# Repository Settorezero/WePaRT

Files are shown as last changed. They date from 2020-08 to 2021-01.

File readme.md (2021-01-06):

  

# WePaRT

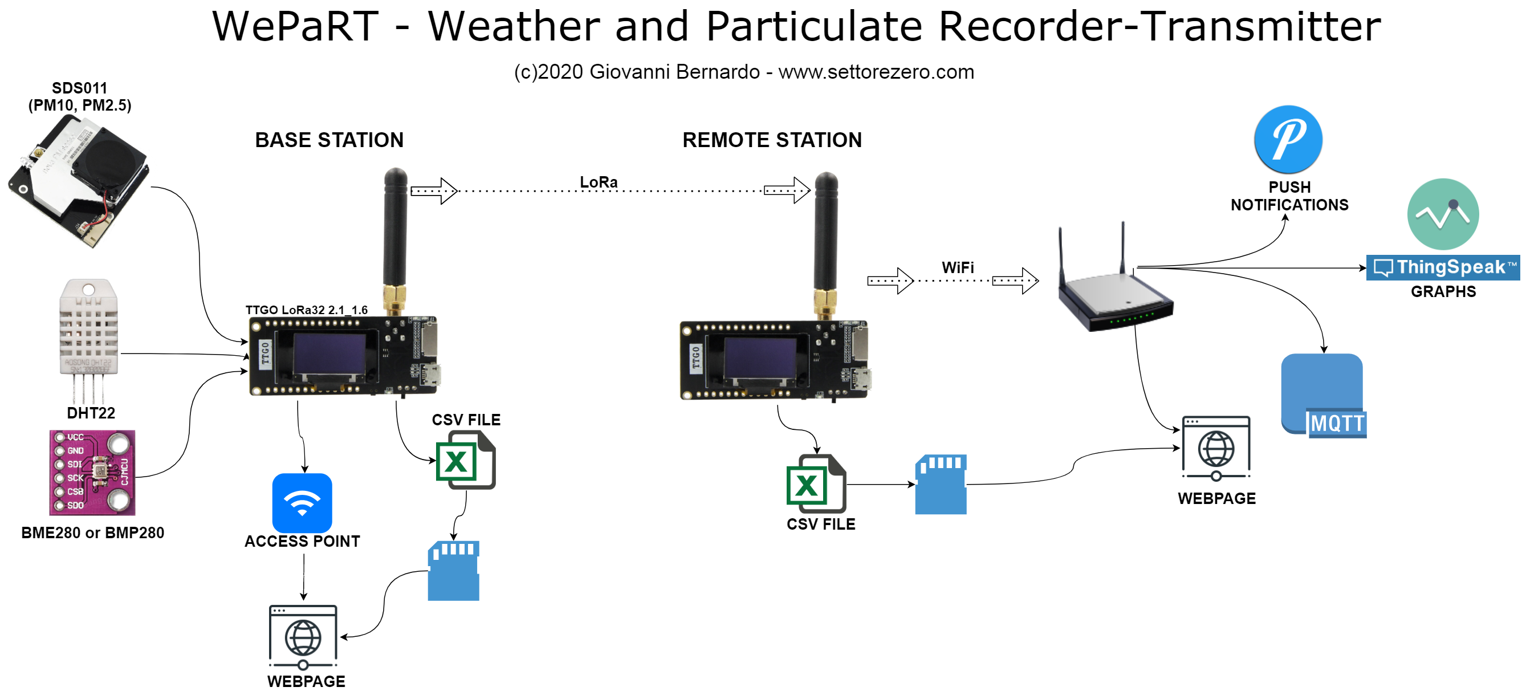
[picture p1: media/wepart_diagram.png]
WePaRT diagram


This project is based on the LiLyGO TTGO LoRa32 version 2.1_1.6 and is composed of two parts:  
- A Base Station
- A Remote Station

### Base Station
Think of this as a station that is placed where WiFi and/or Telephone is not accessible.  
Is the one where sensors are attached. Actually those sensors are used:  
- DHT22 (humidity, temperature)
- BME280 (pressure, temperature, humidity) Or BMP280 (pressure, temperature)
- SDS011 (particulate matter: PM10 and PM2.5)  

Base station gets data from sensors and:
- Save them on a microSD card in CSV format
- propagate them through LoRa to the Remote Station
- act as an access point for showing real-time data on a webpage

### Remote Station
Is the one attached to a WiFi infrastructure. Receives data from the Base Station and:
- transmits them to Thingspeak for graph generation
- transmits them over MQTT
- saves the good received data in a CSV, adding the current time/date taken from an NTP server
- saves the bad received data in a text file for further analisys of bad received packets
- shows a webpage by navigating to his IP address in the same wifi network were device is connected

### Documents
- In the [STL Folder](/stl) are contained the STL parts to be 3D-printed.
- In the [docs Folder](/docs) are contained Datasheets and schematics.
- In the [Arduino Folder](/arduino) are contained the programs to be uploaded on the Stations

### Known Problems
- showing always some data, OLED's pixel burns out so will remain a "shadow". Solution (not yet implemented): a function like a screensaver
- if the connected SD broke up, the station wouldn't start-up since the connected SD can be detected but will fail other functions giving an unexpected behaviour that can lead to a continuos reset. Since the remote station can be placed in a place where is not visibile, if this happens, we will never see a failure: we will see the base station showing always the same data. Solution (not yet implemented): detect a timeout on the base station

### Links
- You can read a full description of the WePaRT on the [settorezero blog](https://www.settorezero.com/wordpress/wepart-stazione-monitoraggio-meteo-polveri-sottili-particolato)
- You can see actual data sent to Thingspeak by our WePaRT [here](https://thingspeak.com/channels/1107465)
- [This](http://www.bahar.asia/Product/26/name?BWP-10008-A2) is the enclosure I've used for the Remote Station

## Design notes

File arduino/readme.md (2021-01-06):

## WePaRT Source Code  

Source code is intended to be used along Arduino IDE.  
There is a source code for the base station and another one for the remote station.
You need to install the ESP32 support for Arduino IDE.

### Libraries to install

- [Thingspeak-Arduino](https://github.com/mathworks/thingspeak-arduino) (by Mathworks)
- [EasyNTPClient](https://github.com/aharshac/EasyNTPClient) (by Harsha Alva)
- [Time](https://github.com/PaulStoffregen/Time) (by Michael Margolis)
- [PubSubClient](https://github.com/knolleary/pubsubclient) (by Nick O’Leary)
- [Adafruit DHT sensor](https://github.com/adafruit/DHT-sensor-library)
- [Adafruit Unified Sensor](https://github.com/adafruit/Adafruit_Sensor)
- [Adafruit BME280](https://github.com/adafruit/Adafruit_BME280_Library)
- [LoRa](https://github.com/sandeepmistry/arduino-LoRa) (by Sandeep Mistry)
- [ESP8266 and ESP32 Oled Driver for SSD1306 Displays+](https://github.com/ThingPulse/esp8266-oled-ssd1306) (by ThingPulse)

If you want to use Pushover for Push Notifications, you must install also [Pushover by Arduino Hannover](https://github.com/ArduinoHannover/Pushover). You can copy the two files Pushover.cpp and Pushover.h in the `wepart_remote_station/` folder

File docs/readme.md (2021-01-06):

## WePaRT DOCS and LINKS

In this folder are located the useful documents and links for better working with the WePaRT.  

### Documents
- [Base Station Schematic](schematic_base_station.png)
- [SDS011 Datasheet](SDS011_datasheet.pdf)
- [SDS011 Protocol Specifications, Rev. 1.3](SDS011_Protocol_V1.3.pdf)
- [BME280 Datasheet](bme280_datasheet.pdf)
- [BME280 Design guide](bme280_design_guide.pdf)
- [LiLyGO TTGO LoRa32 2.1_1.6 Schematic](LoRa32_schematic.pdf)

### Links
- [SDS11 - things to know](https://www.settorezero.com/wordpress/il-sensore-sds011-e-le-polveri-sottili/)
- [BME280, BMP280 - things to know](https://www.settorezero.com/wordpress/sensori-di-pressione-bme280-e-bmp280/)
- [The LiLyGO TTGO LoRa 2.1_1.6 - Part 1](https://www.settorezero.com/wordpress/lora_lorawan_lilygo_ttgo_lora32_esp32/)
- [The LiLyGO TTGO LoRa 2.1_1.6 - Part 2](https://www.settorezero.com/wordpress/lilygo_ttgo_lora32_esp32_point_to_point/)

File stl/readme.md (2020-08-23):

## WePaRT STL Files
In this folder are placed the STL files we used for the WePaRT.  
There are 2 STL Files created by @CyB3rn0id and another to be downloaded from Thingiverse.

### STL Files
- [funnel](funnel.stl) - This is used as air conveyour
- [funnel grid](funnel_grid.stl) - Simple grid to be placed on top of funnel

### Thingiverse
- [Stevenson Screen by cybershifter](https://www.thingiverse.com/thing:4529099/files)

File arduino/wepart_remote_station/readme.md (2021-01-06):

## WePaRT Remote Station source code

This is the code you must upload on the module in the Remote Station. The Remote Station is the one connected to WiFi and that receives data over LoRa from the Base for sending them over MQTT and Thingspeak, aka the Receiver Station.

Please remember those things first than upload the code:  
- Remove the microSD card from the slot
- Select the right board in Arduino IDE: <kbd>ESP32 Arduino > TTGO LoRa32-OLED v1</kbd>
- Select the right COM port in Arduino IDE
- Install the right libraries
- change the values in `secret.h` by putting your username/password for WiFi, and eventually for Thingspeak, MQTT Pushover

If you don't want to use Thingspeak comment `#define USE_THINGSPEAK` at row `118` of `wepart_remote_station.ino`.
If you don't want to use MQTT comment `#define USE_MQTT` at row `128` of `wepart_remote_station.ino`.
If you don't want to use Pushover comment `#define USE_PUSHOVER` at row `123` of `wepart_remote_station.ino`.

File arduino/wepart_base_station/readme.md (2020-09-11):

## WePaRT Base Station source code

This is the code you must upload on the module in the Base Station. The Base Station is the one where Sensors are attached, aka the Transmitter Station.  

Please remember those things first than upload the code:  
- Remove the connection between SDS011 and board. The SDS011 implementation uses the hardware UART, the same used for code upload
- Remove the microSD card from the slot
- Select the right board in Arduino IDE: ESP32 Arduino > TTGO LoRa32-OLED v1
- Select the right COM port in Arduino IDE
- Install the right libraries

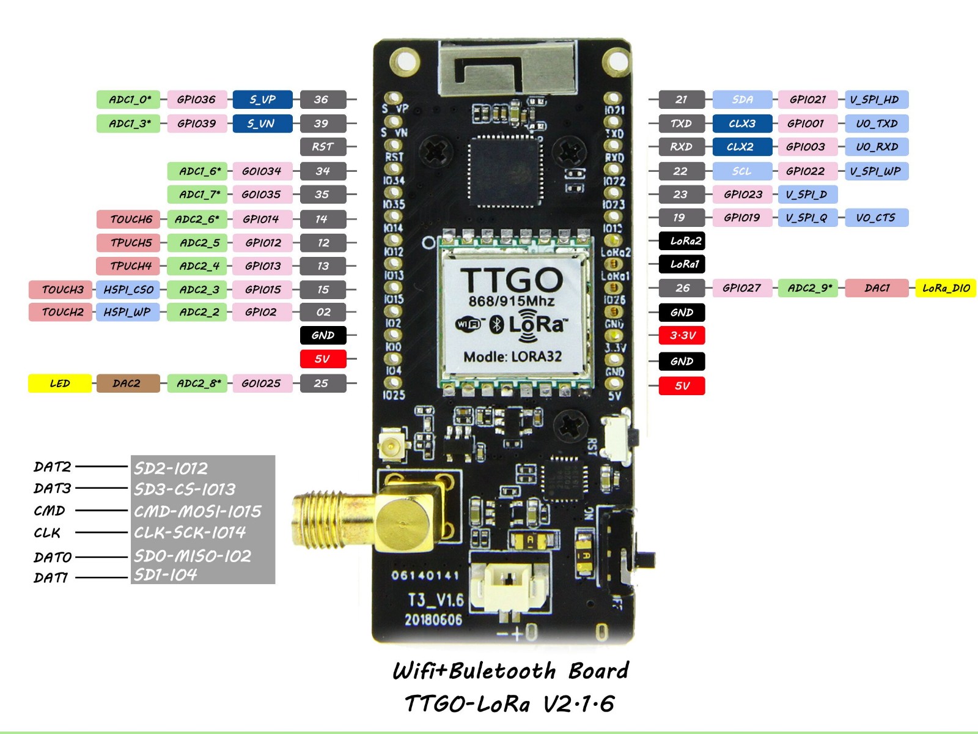
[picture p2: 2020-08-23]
docs/LoRa32_pinout.jpg

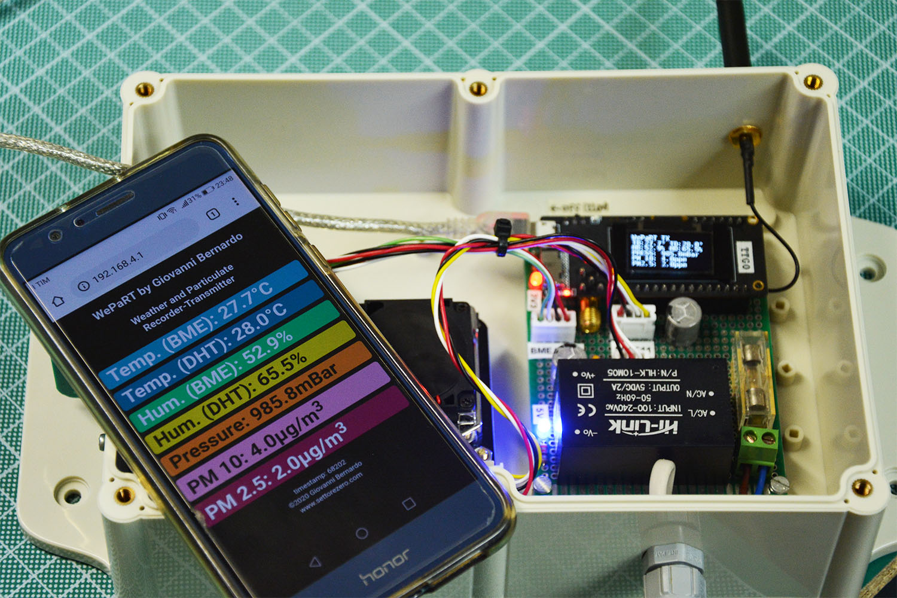
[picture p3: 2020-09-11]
media/wepart_overview.jpg

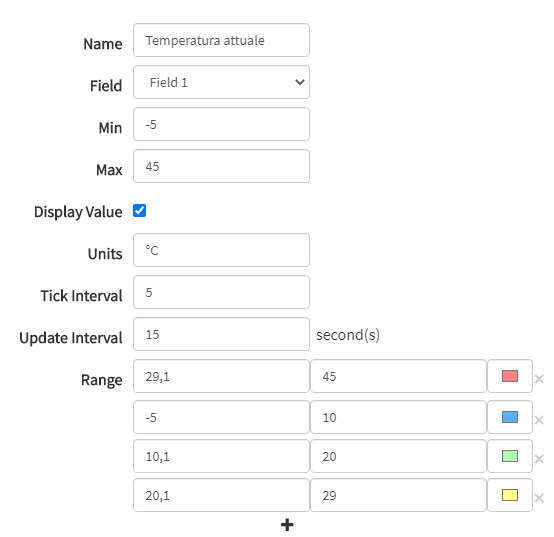
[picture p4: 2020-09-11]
media/thingspeak_gauge_settings.png

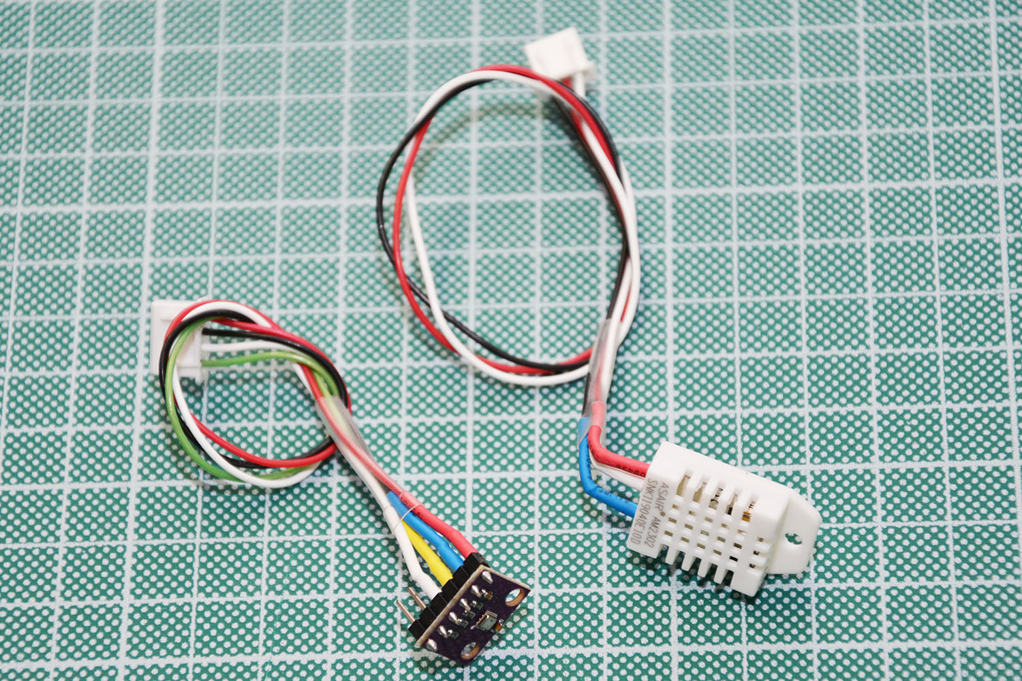
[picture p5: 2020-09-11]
media/wepart_meteo_sensors.jpg

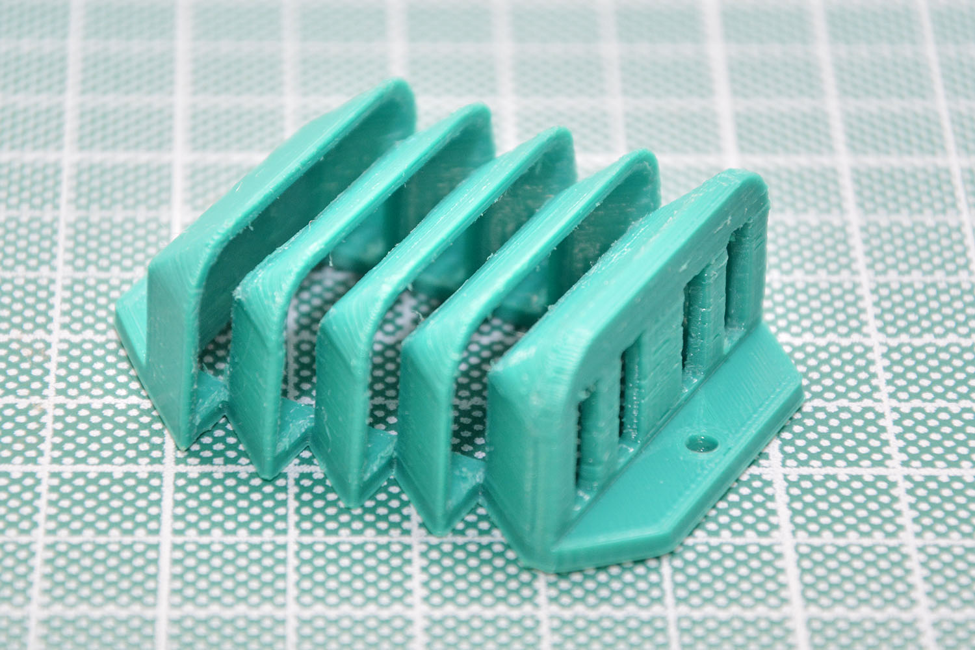
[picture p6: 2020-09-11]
media/wepart_stevenson_screen.jpg

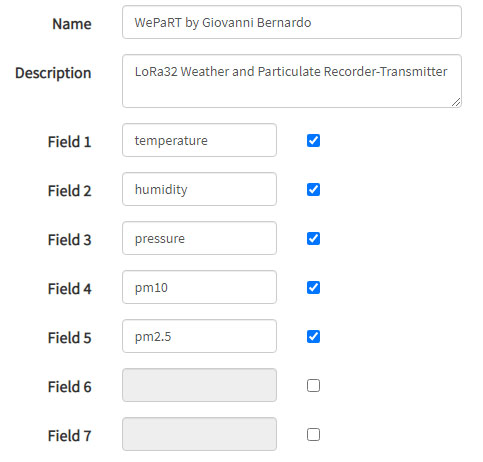
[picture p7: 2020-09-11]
media/thingspeak_channel_settings.jpg

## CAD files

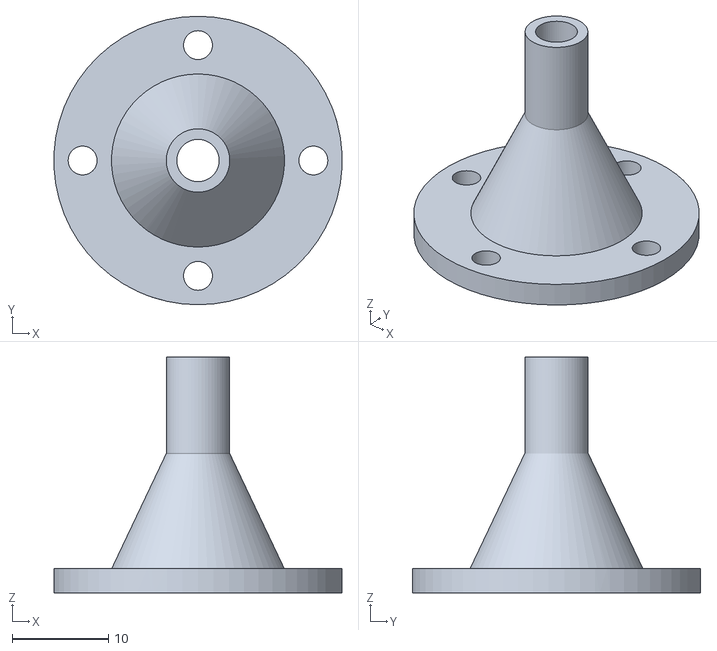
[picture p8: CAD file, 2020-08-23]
stl/funnel.stl
30.0 x 30.0 x 24.5

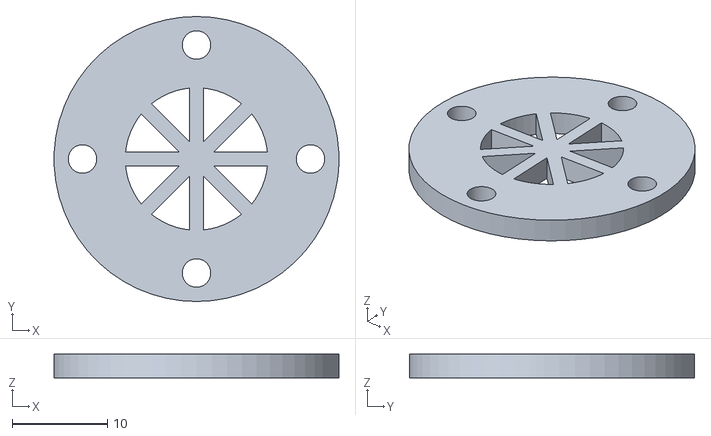
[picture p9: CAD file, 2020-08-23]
stl/funnel_grid.stl
30.0 x 30.0 x 2.50

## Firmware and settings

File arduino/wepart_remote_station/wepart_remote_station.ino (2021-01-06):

/*
 * WePaRT - Weather and Particulate Recorder Transmitter
 * REMOTE STATION
 * Version 1.1
 * board used: LILYGO® TTGO LoRa32 V2.1_1.6
 * 
 * Code and design by Bernardo Giovanni aka CyB3rn0id (https://www.settorezero.com)
 * If you want to share the code please mention: Giovanni Bernardo of settorezero.com
 * after sending me a message
 *
 * For further information please read the article at:
 * https://www.settorezero.com/wordpress/wepart-stazione-monitoraggio-meteo-polveri-sottili-particolato
 *
 * Repo URL:
 * https://github.com/Settorezero/WePaRT
 * 
 * Select the board ESP32 Arduino > TTGO LoRa32-OLED v1 
 *
 * Libraries required for this part of code:
 * Adafruit DHT Sensor: https://github.com/adafruit/DHT-sensor-library
 * Adafruit Unified Sensor: https://github.com/adafruit/Adafruit_Sensor
 * Adafruit BME280: https://github.com/adafruit/Adafruit_BME280_Library
 * LoRa by Sandeep Mistry: https://github.com/sandeepmistry/arduino-LoRa
 * ESP8266 and ESP32 Oled Driver for SSD1306 Displays by Thingpulse: https://github.com/ThingPulse/esp8266-oled-ssd1306
 * EasyNTP client - https://github.com/aharshac/EasyNTPClient
 * PubSub client - https://github.com/knolleary/pubsubclient
 * TimeLib - https://github.com/PaulStoffregen/Time
 * Thingspeak - https://github.com/mathworks/thingspeak-arduino
 * 
 * If you want to use Pushover for Push Notifications, you must install also
 * Pushover by Arduino Hannover - https://github.com/ArduinoHannover/Pushover
 * (you can copy the two files Pushover.cpp and Pushover.h in this folder)
 *
 * LICENSE
 * Attribution-NonCommercial-ShareAlike 4.0 International 
 * (CC BY-NC-SA 4.0)
 * 
 * WARNING: this license may be valid for the project (design, schematics, diagrams, own documentation, solutions to problems, ideas)
 * and for my own written code (some routines and ideas). 
 * Is not appliable for used libraries and commercial used hardware.
 * Please read licenses for every library used and hardware.
 * 
 * This is a human-readable summary of (and not a substitute for) the license:
 * You are free to:
 * SHARE — copy and redistribute the material in any medium or format
 * ADAPT — remix, transform, and build upon the material
 * The licensor cannot revoke these freedoms as long as you follow the license terms.
 * Under the following terms:
 * ATTRIBUTION — You must give appropriate credit, provide a link to the license, 
 * and indicate if changes were made. You may do so in any reasonable manner, 
 * but not in any way that suggests the licensor endorses you or your use.
 * NON COMMERCIAL — You may not use the material for commercial purposes.
 * SHARE ALIKE — If you remix, transform, or build upon the material,
 * you must distribute your contributions under the same license as the original.
 * NO ADDITIONAL RESTRICTIONS — You may not apply legal terms or technological 
 * measures that legally restrict others from doing anything the license permits.
 * 
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
 * Please read the Full License text at the following link:
 * https://creativecommons.org/licenses/by-nc-sa/4.0/legalcode
 *
 */

#include <WiFi.h>
#include <WebServer.h>
#include <SD.h>
#include <SPI.h>
#include <LoRa.h>
#include <Wire.h> 
#include <SSD1306Wire.h>
#include <WiFiUdp.h>
#include <EasyNTPClient.h>
#include <TimeLib.h>
#include <PubSubClient.h>
#include "ThingSpeak.h"

#include "board_defs.h" // in this header I've defined the pins used by the module LILYGO® TTGO LoRa32 V2.1_1.6
#include "images.h"
#include "my_fonts.h"
#include "webpage.h"
#include "secret.h"

// If you want to use Pushover for Push Notifications, you must install also
// Pushover by Arduino Hannover - https://github.com/ArduinoHannover/Pushover
// (you can copy the two files Pushover.cpp and Pushover.h in this folder)
#include "pushover.h"

// START OF CUSTOMIZE SECTION --------------------------------------------------------------------------------------------------------------------

// **************************************
// WI-Fi Network settings
// **************************************
#define RETRIES_WIFI 100  // number of WiFi re-connection retries after a no-connection, at 500mS reconnection rate
#define USE_STATIC_IP // comment for using DHCP OR if you have errors on NTP server connection
// if you want to use static IP, change also following parameters:
// WARNING:
// the better thing is to assign static IP directly from the router
#ifdef USE_STATIC_IP
    IPAddress deviceIP(192, 168, 1, 162); // static address will be assigned to the device
    IPAddress gateway(192, 168, 1, 1); // router address
    IPAddress subnet(255, 255, 255, 0); // subnet mask, usually you don't need to change this value
    // following are Google DNS, you don't really need to change them
    IPAddress dns1 (8, 8, 8, 8); // first DNS, required for easyntp with static ip (https://github.com/aharshac/EasyNTPClient/issues/4)
    IPAddress dns2 (8, 8, 4, 4); // second DNS, required for easyntp with static ip
#endif

// **************************************
// THINGSPEAK settings
// **************************************
#define USE_THINGSPEAK // comment if you don't want to use thingspeak

// **************************************
// PUSHOVER settings
// **************************************
#define USE_PUSHOVER // comment if you don't want to use pushover

// **************************************
// MQTT settings
// **************************************
#define USE_MQTT // comment if you don't use an MQTT server
#define MQTT_RETRIES 5  // number of MQTT re-connection retries after a no-connection
#define MQTT_SOCKET_TIMEOUT 2 // seconds for MQTT server response timeout
#define MQTT_USE_PASSWORD // Comment this if your MQTT server does not require user/password
IPAddress mqtt_server(192,168,1,101); // this is the address of your MQTT server
const uint16_t mqtt_port=1883; // this is the port where your MQTT server is listening. 1883 is the standard value
const char* mqtt_clientID = "WePaRT"; // unique name for this MQTT client, you can leave WePaRT
const char* topic_wepart="wepart"; // MQTT topic where message will be published

// **************************************
// NTP settings
// **************************************
// WARNING: use DHCP (NO static IP) if you encounter problems with NTP server
// NTP server returns UTC time. Italy use the CET (Central European Time). 
// during the ST (Standard Time="ora solare" in italian language) CET=UTC+1
// during the DST (Daylight Saving Time="ora legale" in italian language) CET=UTC+2
// DST starts at 2:00AM of the last Sunday of March and ends at 3:00AM of the last Sunday of October
#define TIME_OFFSET 1 // local time offset during Standard Time (Italy uses CET=UTC+1)
const char* NTPServer="it.pool.ntp.org"; //"ntp1.inrim.it";  // NTP server, use one of your country
#define NTP_RETRY_MINUTES 10  // if first NTP connection gone bad, I'll retry after those minutes

// **************************************
// OTHER settings
// **************************************

// uncomment for verbose messages on the serial port (115200 baud)
#define DEBUG

// remove comment if you want a fast-startup (no delays, nor logos during initializazion - used mainly for a rapid check of the code after debug)
//#define FASTINIT

// normal pressure at 25° at my altidude
// I used the calculator at https://www.mide.com/air-pressure-at-altitude-calculator
// not used in the code, here for future implementations
float nPressure=983.4253; // hPa = mBar

// pm10, pm2.5 limits for pushover notifications
float pm10limit=40;
float pm25limit=20;

// END OF CUSTOMIZE SECTION ----------------------------------------------------------------------------------------------------------------------
// do not change nothing below

// variables used for this (remote) station
bool sdpresent=false; // keep in mind if there is an SD card mounted
String rssi = "--"; // received signal strength indicator value
float mybattery=0; // battery voltage on this device (not the base station)
bool datavalid=false; // keep in memory if received packet over LoRa is good
String dataFile=""; // file name where data will be saved on the SD card
bool firstStart=true; // used for first time file-creation on first valid received data
const char* badPacketFile="/badpack.txt"; // file where bad packets will be saved, don't forget the / in front of filename!

// variables used for Time keeping
bool clockIsSet=false; // flag that indicates that the time was updated the first time at startup
int8_t prevDay=-1; // used for time refresh once a day or for forcing time update
String wd[7]={"dom","lun","mar","mer","gio","ven","sab"}; // name of weekdays, 9 chars max length in italian
String mo[12]={"Gen","Feb","Mar","Apr","Mag","Giu","Lug","Ago","Set","Ott","Nov","Dic"}; // name of months

// good received data from base station
uint8_t fields=0; // number of transmitted fields
String basetimestamp=""; // timestamp from remote station
String battery="-.-"; // base station battery voltage
String sdstatus="-"; // base station SD status: -1=not mounted, 0=full, 1=working
// data from BME280/BMP280
String pressure="---.-";
String temperatureB="--.-";
String humidityB="--.-"; // not used if your base station has the BME280 instead of the BMP280
// data from DHT22
String temperatureD="--.-";
String humidityD="--.-";
// data from SDS011
String pm10="---";
String pm25="---";
String pmIsNew="0";
bool stoprecording=false; // for future use to stop the SD saving
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
void loop() 
  {
  static bool lastDst=checkDST(); // DST status, used for forcing time update since normally will occur after 00:00
 
  // check for wifi/MQTT connection
  wl_status_t wifiStatus = WiFi.status();
  if(wifiStatus != WL_CONNECTED)
    {
    wifi_connect();
    }
  #ifdef USE_MQTT
  else if (!MQTTClient.loop()) // needed for mantaining MQTT connection, returns connection status
      {
      #ifdef DEBUG
        Serial.println("MQTT disconnected");  
      #endif
      #ifdef MQTT_USE_PASSWORD
          MQTTClient.connect(mqtt_clientID,mqtt_user,mqtt_password);
      #else
          MQTTClient.connect(mqtt_clientID);
      #endif
      }
  #endif

  // doing the Webserver required stuff
  server.handleClient();
  
  // check if clock update if needed every hour
  if (clockIsSet) 
    {
    bool dst=checkDST(); // check if we're in DST for forcing time update
    if (lastDst!=dst)
      {
      if(updateTime(true)) lastDst=dst;
      }
   else
      {
      updateTime(false); // normal update once a day after 00:00
      }
    } // \clockIsSet
  else
    {
    if(updateTime(true)) lastDst=checkDST();
    }
    
   // write stuff on the oled display
  display.clear();
  display.setTextAlignment(TEXT_ALIGN_LEFT);
  display.setFont(Monospaced_bold_11);
  display.drawString(0,0, "WePaRT RX ["+rssi+"]");
  display.drawString(0, 10,"TB:"+temperatureB+"° TD:"+temperatureD+"°"); // temperature from the BME280/BMP280 - Temperature from the DHT22
  if (fields==12)
    {
    display.drawString(0, 20,"HB:"+humidityB+"% HD:"+humidityD+"%"); // humidity from the BME280 - Humidity from the DHT22
    }
  else
    {
    display.drawString(0, 20,"Hu: "+humidityD+"%"); // humidity from the DHT22
    }
  display.drawString(0, 30,"PRESS: "+pressure+"mBar"); // pressure
  display.drawString(0, 40,"PM 10: "+pm10+"ppm"); // PM10 value (whole, contains also the PM2.5)
  display.drawString(0, 50,"PM2.5: "+pm25+"ppm"); // PM2.5 value
  display.display();

  int packetSize=LoRa.parsePacket();
  if (packetSize) getLoRaPacket(packetSize);
  }

/******************************************************************************************************************
* Receive LoRa Packet and transmit data
******************************************************************************************************************/
void getLoRaPacket(int packetSize) 
  {
  datavalid=false; // become true?
  LedOn();
  String packet=""; // reset the received packet string
  String error=""; // error description if any
  String packetField[13]; // separate fields of the packet
  String packSize=String(packetSize,DEC); // bytes of the packet (was passed to the function)
  rssi=String(LoRa.packetRssi(), DEC); // received signal strength indicator
  // re-construct packet char by char
  for (int i=0; i<packetSize; i++) 
    {
    packet +=(char)LoRa.read(); 
    }
  
  #ifdef DEBUG
    Serial.print("Packet received: ");
    Serial.println(packet);
    Serial.print("RSSI: ");
    Serial.println(rssi);
  #endif

  // set the timestamp first than all other things
  String mytimestamp=setNiceTimeStamp();
    
  // packet must start with @ and end with #
  if ((packet.startsWith("@") && packet.endsWith("#")))
    {
    // Received packet is composed as:
    // https://docs.google.com/spreadsheets/d/1uwv2ZbNlVsGTnG6Q6OH3sNCoVa-4uajZjfyRlMmH_ik/edit?usp=sharing
   
    // I must remove the @ and the #
    String upacket=packet.substring(1,packet.length()-1);
    
    // parse the packet
    int cc=0; // field separator counter
    int k=-1; // first substring must start from index 0 and I add 1 for others
    // scanning in search of separators one char at time
    for (int i=0; i<upacket.length(); i++) 
        {
        if (upacket.substring(i, i+1)==";") // found the field separator
            {
            packetField[cc]=upacket.substring(k+1,i); // extract field from next char after previous comma until this char
            k=i; // keep in mind the position of last ; found
            cc++; // ; counter is the same of field counter
            } // \; found
        } // \for
    
    // last element has no ; after it and it's the checksum value. I must extract it from the last ; to the end of the string
    packetField[cc]=upacket.substring(k+1,upacket.length());
    
    // scan for null characters in the packets (I don't use them in my packet)
    bool nullChars=false;
    for (int o=0; o<cc+1; o++) // scan all packets
      {
      for (int p=0; p<packetField[o].length(); p++) // scan single packet chars
        {
        if ((packetField[o].charAt(p)<32) || (packetField[o].charAt(p)==127))
          {
          nullChars=true;
          break;      
          }
        }
      if (nullChars) break;
      }

    // if there are no null chars I can continue
    if (!nullChars)
      {
      // check the checksum (lol)
      uint16_t chkR=packetField[cc].toInt(); // checksum contained in the packet (last field), number format
      uint16_t chk=myChecksum(upacket.substring(0,upacket.lastIndexOf(';'))); // calculate actual packet checksum excluding last part with comma and checksum
      if (chk==chkR)
        {
        datavalid=true; // 'till now, data seems valid
        }
      else
        {
        error="Checksum Error. In packet:"+String(chkR)+" Calculated:"+String(chk);
        }
    
      // check the number of fields in the packet
      // number of transmitted fields is the first (0) field
      // number of counted fields is the variable cc, that counts the number of field separators
      if (datavalid)
        {
        uint8_t u=0;
        if (packetField[0]=="12") 
          {u=12;}
        else if (packetField[0]=="11")
          {u=11;}
    
        if (cc==u)
            {
            datavalid=true; // data are really valid
            fields=u; // number of fields
            }
        else    
            {
            datavalid=false; // sorry... reassign false to datavalid
            error="Bad fields count. In packet:"+packetField[0]+" counted:"+String(cc);
            }
        } // checksum ok, i checked the fields number
      } // !nullChars
    else
      {
      // there are nullchars
      datavalid=false;
      error="Null chars in packet";
      }
   } // correct header and tail
  else
    {
    //not correct head and tail
    error="Missing delimiters";
    }

  // data valid => transfer in global used variables, record a new packet on the SD, send data to the world
  if (datavalid)
    {
    basetimestamp=packetField[1];
    temperatureB=packetField[2];
    temperatureD=packetField[3];
    if (fields==12) // base station has the BME280, so there is humidity value from it
        {
        humidityB=packetField[4];
        humidityD=packetField[5];
        pressure=packetField[6];
        pm10=packetField[7];
        pm25=packetField[8];
        pmIsNew=packetField[9];
        battery=packetField[10];
        sdstatus=packetField[11];
        }
    else // base station has the BMP280, so there is no humidity value from pressure sensor
        {
        humidityD=packetField[4];
        pressure=packetField[5];
        pm10=packetField[6];
        pm25=packetField[7];
        pmIsNew=packetField[8];
        battery=packetField[9];
        sdstatus=packetField[10];
        }    

    // reconstruct the new packet: it will be used for saving it onto the SD card or for sending it via MQTT
    // if SD is not mounted and MQTT is not used, this packet will not used anyway
    String npacket=setNewPacket();
    
    // save entire packet on SD if present by adding the current timestamp on this device
    // so in case of loss of data you can compare the timestamps on the SD cards
    if (sdpresent) saveDataToSD(npacket, mytimestamp);

    // send entire packet over MQTT
    #ifdef USE_MQTT
        sendDataOverMQTT(npacket, mytimestamp);
    #endif
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

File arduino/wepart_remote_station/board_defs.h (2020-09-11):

/*
 * Pin definitions for LILYGO® TTGO LoRa32 V2.1_1.6
 * This file cannot be used with other boards even if are similar
 * By Giovanni Bernardo (https://www.settorezero.com)
 * Read the full article here:
 * https://www.settorezero.com/wordpress/lilygo_ttgo_lora32_esp32_point_to_point
 * if you want to share the code please mention: Giovanni Bernardo of settorezero.com
 */

// LoRa Chip, we'll use the LoRa on the VSPI module (SPI3)
// since the VSPI is normally tied to pins 5, 18, 19 and 23
// even if we'll re-arrange them
#define LORA_SCK      5
#define LORA_MISO     19
#define LORA_MOSI     27
#define LORA_SS       18
#define LORA_RST      23
#define LORA_DI0      26
#define LORA_BAND     915E6  // Values: 433E6, 866E6, 915E6 => Check you country, module and Antenna!

// OLED Display (SSD1306 128x64)
#define OLED_SDA      21
#define OLED_SCL      22
#define OLED_ADDRESS  0x3C

// SD Card, wel'll use the SD Card on the HSPI module (SPI2)
// since the HSPI is normally tied to pins 12, 13, 14 and 15
// even if we'll re-arrange then
#define SDCARD_MOSI   15  // CMD
#define SDCARD_MISO   2   // DAT0
#define SDCARD_SCK    14
#define SDCARD_CS     13  // DAT3
#define SDCARD_DAT1   4   // not really used
#define SDCARD_DAT2   12  // not really used

// Others
#define LED           25 // the green led near the on/off button
#define VBAT          35 // Analog Input from 1:2 voltage divider on LiPo Battery

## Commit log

2020-08-23 uploaded LoRa32 Schematic
2020-08-23 added sds011 consented mounting
    It's already present in the datasheet however
2020-08-23 added funnel
    [funnel.stl, funnel_grid.stl]

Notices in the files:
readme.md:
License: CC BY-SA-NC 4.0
